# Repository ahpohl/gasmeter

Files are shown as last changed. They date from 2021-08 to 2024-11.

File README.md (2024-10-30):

# Overview

This project is about reading the counter of [diaphragm gas volume meter](https://en.wikipedia.org/wiki/Gas_meter) which is commonly installed in residential properties to count and bill the consumed gas. The last dial of the meter has a reflective sticker, which can be utilised to detect a full revolution of the dial.

In some meters the reflective sticker is made from a magnetic material and a very sensitive magnetometer is sufficient to detect the changes in the earth magnetic field when the sticker passes by the sensor. In the first version of this project used the [SparkFun 3-axis magnetometer](https://www.sparkfun.com/products/retired/12670) to detect a full revolution of the .001 m³ digit wheel. Since my gas meter was replaced with a new non-magnetic version, the magenetometer sensor doesn't work anymore.

Here I describe a new sensor device, which uses an infrared LED and a phototransistor to detect the changes in reflectivity when the reflective sticker on the last dial passes by the phototransitor. The measurement principle was inspired by the [pulsemeter](https://github.com/ahpohl/pulsemeter) and the device looks like this when mounted in front of the gas meter:

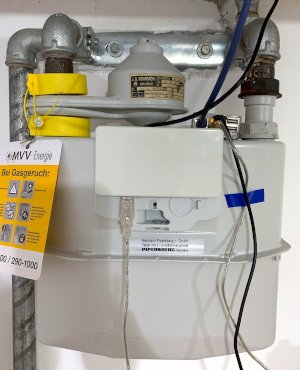
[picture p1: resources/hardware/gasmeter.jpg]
gasmeter


The schematics, board layout and part list of the gasmeter dongle hardware is described in more detail in the [Gasmeter wiki](https://github.com/ahpohl/gasmeter/wiki).

On the software side, the Gasmeter program reads the current gas volume from the meter and forwards it to a MQTT broker on the network. The data is stored in a TimescaleDB database and visualised on a Grafana dashboard. The installation of the software stack, including the setup and maintainance of the database, is described on the [Smartmeter](https://github.com/ahpohl/smartmeter/wiki) wiki pages.

## Build instructions

To compile Gasmeter from source, a Makefile for (cross-)compilation is provided:

```
make CROSS_COMPILE=aarch64-unknown-linux-gnu
make install
```

Alternatively, there is also an Arch Linux package called [gasmeter](https://aur.archlinux.org/packages/gasmeter) published in the AUR.

The hardware dongle needs firmware for the Atmel microcontroller in order to communicate with the gasmeter program. To compile the firmware, first install the AVR toolchain through your package manager. On Arch Linux, install `avr-gcc` and `avr-libc` packages and then `make upload` to compile and upload the firwmare. On a new microcontroller, a bootloader needs to be flashed first to accept a firmware image via upload. The preparation of a new µC is described in the [wiki](https://github.com/ahpohl/gasmeter/wiki).

## Installation

The Arch Linux package provides a systemd service file and installs the configuration file in `/etc/gasmeter/gasmeter.conf`. The service can be started with:

```
systemctl start gasmeter
```

When building directly from source, the daemon can be directly started with:

```
gasmeter --config resources/config/gasmeter_example.conf

```

## Run in Docker

The Arch Linux package installs a docker compose in `/etc/gasmeter/docker-compose.yaml` and a `Dockerfile`. Alternatively, these files are also in the root folder or the source. Before building and starting the container, the serial device used by the gasmeter hardware needs to be set in `docker-compose.yaml` in addtion to `gasmeter.conf` to give Docker access to the device.

```
docker-compose up --build
```

## Configuration

The Gasmeter program is configured with a configuration file located in `/etc/gasmeter/gasmeter.conf`. At least the serial device of the hardware, the MQTT hostname and topic to publish to needs to be set. Optionally, Gasmeter supports MQTT password authentication and TLS connection encryption. Finally, the gas tariff, which consists price per kWh, a yearly service charge and the gas conversion factor (found on the last bill), needs to be set here for the current bill to be shown on the dashboard.

On first run, the low and high threshold parameters need to be determined. For this, there is a special `raw_mode` option in the config file, which outputs the raw sensor values to the console. To record values create a log file with:

```
gasmeter --config gasmeter.conf | tee raw_values.log
```

Plotting the raw values gives a diagram like this (the gnuplot script is provided in the resources folder):

```
gnuplot < sensor.gnuplot > threshold_levels.png
```

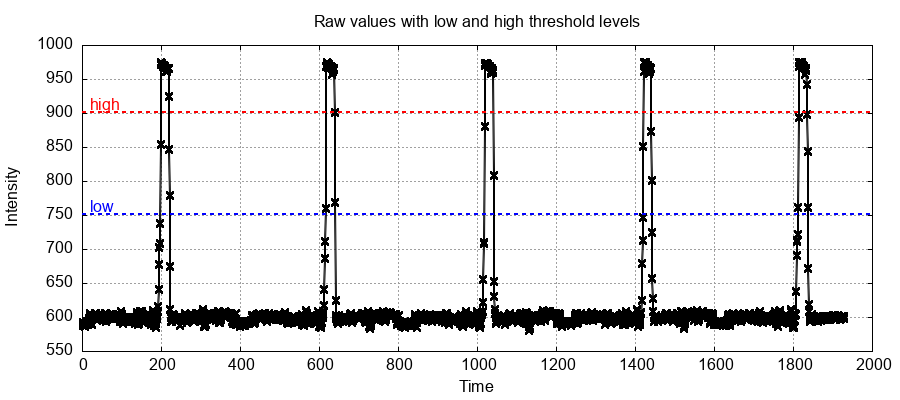
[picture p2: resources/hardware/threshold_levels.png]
Low and high threshold levels


The threshold level low needs to be set slightly above the baseline and level high below the maximum of the raw value. The larger the difference between the baseline and the maximum, the better the tolerance against noise and variations in reflected light intensity. Here the baseline is around 600 and the maximum at 950-1000 and a low level of 750 and high level of 900 works well.

A minimal `gasmeter.conf` config file looks like this:

```
serial_device /dev/ttyUSB0
mqtt_broker localhost
mqtt_topic gasmeter
gas_rate 261.80
gas_price 0.0583
gas_factor 10.835
level_low 750
level_high 900
```

## JSON output

Example JSON published by Gasmeter in the `gasmeter/live` topic:

```
{
  "time":1730287096822, # timestamp, secs since epoch
  "volume":4207.18,     # gas volume, m³ 
  "state":0,            # detection of volume change
  "rate":235.40,        # yearly service rate
  "price":0.1042,       # price per kWh, € (or whatever)
  "factor":11.048       # gas conversion factor, kWh*m³
}
```

## Future development

* Replace the host running gasmeter with an ESP32 version mounted directly on the PCB
* Web interface with MQTT and firmware download capability
* ESP32 version inspired by [AI-on-the-edge](https://github.com/jomjol/AI-on-the-edge-device) and the [Opentherm gateway](https://www.nodo-shop.nl/en/featured/211-opentherm-gateway.html)

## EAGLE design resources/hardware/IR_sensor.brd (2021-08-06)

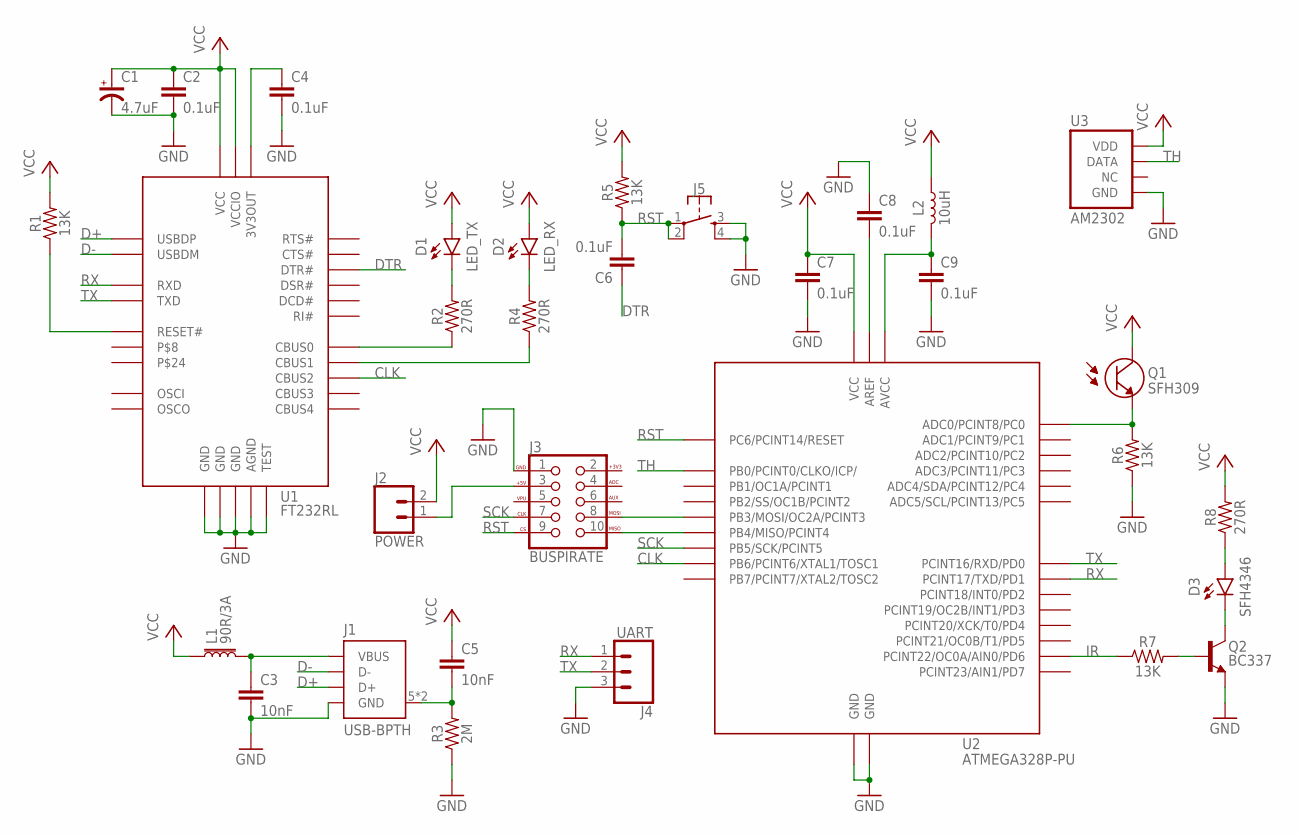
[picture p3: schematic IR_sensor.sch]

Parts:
C1: 4.7uF; CPOL-RADIAL-2.5MM-5MM
C2, C4, C6, C7, C8, C9: 0.1uF; CAP-PTH-5MM
C3: 10nF; CAP-PTH-2.5MM
C5: 10nF; CAP-PTH-5MM
D1: LED_TX; LED_5MM
D2: LED_RX; LED_5MM
D3: SFH4346; LED_3MM_R
J1: USB-BPTH; USB-B-PTH
J2: POWER; 1X02
J3: BUSPIRATE; 2X5-SHROUDED
J4: UART; 1X03
J5: SWITCH; TACTILE_SWITCH_PTH_6.0MM
L1: 90R/3A; AXIAL-0.3
L2: 10uH; AXIAL-0.4
Q1: SFH309; LED_3MM_R
Q2: BC337; TO-92
R1, R5, R6, R7: 13K; AXIAL-0.3
R2, R4, R8: 270R; AXIAL-0.3
R3: 2M; AXIAL-0.3
U1: FT232RL; TSSOP-28-BL
U2: ATMEGA328P-PU; DIP28
U3: AM2302; SNR4-2.54

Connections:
+3V3: J3.2 (+3V3)
ADC: Q1.A (E), R6.P$2 (2), U2.23 (ADC0/PCINT8/PC0)
CLK: U1.13 (CBUS2), U2.9 (PB6/PCINT6/XTAL1/TOSC1)
D+: J1.3 (D+), U1.15 (USBDP)
D-: J1.2 (D-), U1.16 (USBDM)
DTR: C6.1, U1.2 (DTR#)
GND: C1.2 (-), C2.2, C3.2, C4.2, C7.2, C8.1, C9.2, J1.4 (GND), J3.1 (GND), J4.3, J5.3, J5.4, Q2.1 (E), R3.P$1 (1), R6.P$1 (1), U1.7 (GND), U1.18 (GND), U1.21 (GND), U1.25 (AGND), U1.26 (TEST), U2.8 (GND), U2.22 (GND), U3.P$4 (GND)
IR: R7.P$1 (1), U2.12 (PCINT22/OC0A/AIN0/PD6)
MISO: J3.10 (MISO), U2.18 (PB4/MISO/PCINT4)
MOSI: J3.8 (MOSI), U2.17 (PB3/MOSI/OC2A/PCINT3)
unnamed: C3.1, J1.1 (VBUS), L1.P$2 (2)
unnamed: R1.P$1 (1), U1.19 (RESET#)
unnamed: C4.1, U1.17 (3V3OUT)
unnamed: D1.K, R2.P$2 (2)
unnamed: C8.2, U2.21 (AREF)
unnamed: D2.K, R4.P$2 (2)
unnamed: J2.1, J3.3 (+5V)
unnamed: D3.K, Q2.3 (C)
unnamed: R2.P$1 (1), U1.23 (CBUS0)
unnamed: C5.2, J1.5 (SHIELD), J1.6 (SHIELD), R3.P$2 (2)
unnamed: D3.A, R8.P$1 (1)
unnamed: Q2.2 (B), R7.P$2 (2)
unnamed: C9.1, L2.P$2 (2), U2.20 (AVCC)
unnamed: R4.P$1 (1), U1.22 (CBUS1)
RST: C6.2, J3.9 (CS), J5.1, J5.2, R5.P$1 (1), U2.1 (PC6/PCINT14/RESET)
RX: J4.1, U1.5 (RXD), U2.3 (PCINT17/TXD/PD1)
SCK: J3.7 (CLK), U2.19 (PB5/SCK/PCINT5)
TH: U2.14 (PB0/PCINT0/CLKO/ICP/), U3.P$2 (DATA)
TX: J4.2, U1.1 (TXD), U2.2 (PCINT16/RXD/PD0)
VCC: C1.1 (+), C2.1, C5.1, C7.1, D1.A, D2.A, J2.2, L1.P$1 (1), L2.P$1 (1), Q1.K (C), R1.P$2 (2), R5.P$2 (2), R8.P$2 (2), U1.4 (VCCIO), U1.20 (VCC), U2.7 (VCC), U3.P$1 (VDD)

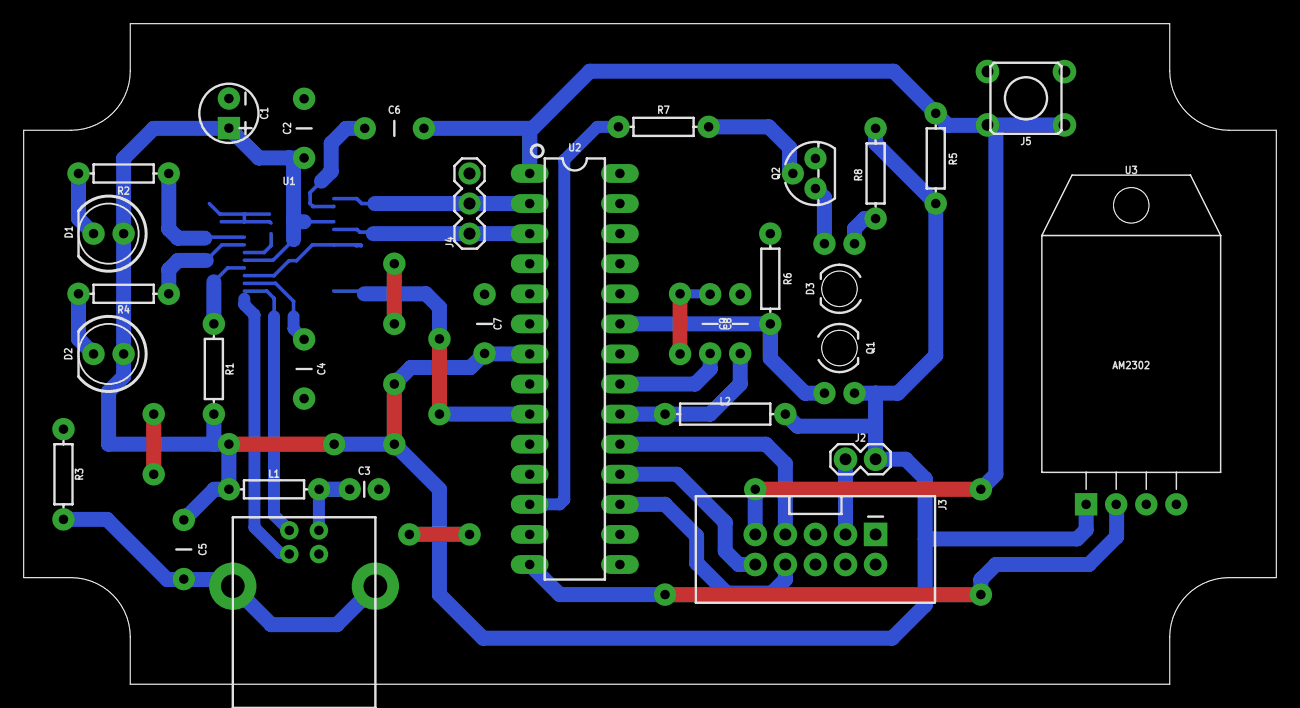
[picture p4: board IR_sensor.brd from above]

Board: 2 copper layers, 105.8 x 55.8 mm, 32 parts (0 on the bottom side), 29 nets.

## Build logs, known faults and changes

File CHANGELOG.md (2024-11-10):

# Gasmeter changelog

## v0.5.5 - 2024-11-10
* fix mqtt port config error

## v0.5.4 - 2024-10-30
* update documentation
* add docker compose support
* mqtt port optional argument
* fix compile errors
* add raw\_mode keyword in config
* calculate time buckets with local time zone

## v0.5.3 - 2023-03-24
* updated retention policies
* remove outer array in json output

## v0.5.2 - 2022-12-29
* fix mqtt status topic not retained
* automatically reconnect to broker

## v0.5.1 - 2022-10-29
* output current reading on startup

## v0.4.6 - 2022-04-02
* improved interrupt signal handling

## v0.4.5 - 2022-04-01
* removed DHT22 sensor code in firmware in daemon
* altered live database table

## v0.4.4 - 2022-03-30
* TimescaleDB: replaced \_time\_bucket() with timescaledb\_experimental.time\_bucket\_ng()
* created yearly\_view
* output state of gas flame in central heater

## v0.4.3 - 2022-01-03
* initial release
* add readme

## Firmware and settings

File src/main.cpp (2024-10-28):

#include <csignal>
#include <future>
#include <getopt.h>
#include <iostream>

#include <Gasmeter.h>

int main(int argc, char *argv[]) {
  bool version = false;
  bool help = false;
  std::string config;

  const struct option longOpts[] = {{"help", no_argument, nullptr, 'h'},
                                    {"version", no_argument, nullptr, 'V'},
                                    {"config", required_argument, nullptr, 'c'},
                                    {nullptr, 0, nullptr, 0}};

  const char optString[] = "hVc:";
  int opt = 0;
  int longIndex = 0;

  do {
    opt = getopt_long(argc, argv, optString, longOpts, &longIndex);
    switch (opt) {
    case 'h':
      help = true;
      break;
    case 'V':
      version = true;
      break;
    case 'c':
      config = optarg;
      break;
    default:
      break;
    }

  } while (opt != -1);

  if (help) {
    std::cout << "Gasmeter " << VERSION_TAG << std::endl;
    std::cout << std::endl << "Usage: " << argv[0] << " -c [file]" << std::endl;
    std::cout << "\n\
  -h --help         Show help message\n\
  -V --version      Show build info\n\
  -c --config       Set config file"
              << std::endl
              << std::endl;
    return EXIT_SUCCESS;
  }

  if (version) {
    std::cout << "Version " << VERSION_TAG << " (" << VERSION_BUILD
              << ") built " << VERSION_BUILD_DATE << " by "
              << VERSION_BUILD_MACHINE << std::endl;
    return EXIT_SUCCESS;
  }

  std::cout << "Gasmeter " << VERSION_TAG << " (" << VERSION_BUILD << ")"
            << std::endl;

  sigset_t sigset;
  sigemptyset(&sigset);
  sigaddset(&sigset, SIGINT);
  sigaddset(&sigset, SIGTERM);
  pthread_sigmask(SIG_BLOCK, &sigset, nullptr);

  std::atomic<bool> shutdown_requested(false);
  std::mutex cv_mutex;
  std::condition_variable cv;

  auto signal_handler = [&]() {
    int signum = 0;
    sigwait(&sigset, &signum);
    shutdown_requested.store(true);
    cv.notify_all();
    return signum;
  };

  auto ft_signal_handler = std::async(std::launch::async, signal_handler);

  std::unique_ptr<Gasmeter> meter(new Gasmeter());
  if (!meter->Setup(config)) {
    std::cout << meter->GetErrorMessage() << std::endl;
    return EXIT_FAILURE;
  }

  auto worker = [&]() {
    int timeout = 0;

    while (shutdown_requested.load() == false) {
      std::unique_lock lock(cv_mutex);
      if (!meter->Receive()) {
        if (timeout < 5) {
          std::cout << meter->GetErrorMessage() << std::endl;
          ++timeout;
        }
        continue;
      } else {
        timeout = 0;
      }
      if (!(meter->IsRawMode())) {
        if (!meter->Publish()) {
          std::cout << meter->GetErrorMessage() << std::endl;
        }
      }
      cv.wait_for(lock,
                  (meter->IsRawMode()) ? std::chrono::milliseconds(40)
                                       : std::chrono::seconds(60),
                  [&]() { return shutdown_requested.load(); });
    }
    return shutdown_requested.load();
  };

  auto worker_thread = (std::async(std::launch::async, worker));

  return EXIT_SUCCESS;
}

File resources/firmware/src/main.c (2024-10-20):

#include "main.h"
#include "gasmeter.h"
#include "millis.h"
#include "uart.h"
#include "util.h"
#include <avr/eeprom.h>
#include <avr/interrupt.h>
#include <avr/io.h>
#include <inttypes.h>
#include <stdio.h>
#include <stdlib.h>
#include <string.h>

// Interrupt service routine for the ADC completion
ISR(ADC_vect) {
  // must read low byte first
  gasmeter.adc_value = (int16_t)ADCL | ((int16_t)ADCH << 8);
}

void ReadAdc(void) {
  if (TCNT0 == (OCR0A + 8)) {
    // trigger single ADC measurement
    ADCSRA |= _BV(ADSC);
  }
}

void ReadGasMeter(void) {
  unsigned long current_millis = millis();
  static unsigned long previous_millis = 0;

  if (((current_millis - previous_millis) > 50)) {
    // evaluate counter
    static uint8_t hysteresis = 0;
    if ((gasmeter.adc_value > gasmeter.level_high)) {
      hysteresis = 1;
      // CLED_PORT &= ~(_BV(CLED_PIN));
    } else if ((gasmeter.adc_value < gasmeter.level_low) && hysteresis) {
      ADCSRA &= ~(_BV(ADEN));
      gasmeter.volume++;
      ADCSRA |= _BV(ADEN);
      eeprom_write_dword(&AddrVolume, gasmeter.volume);
      hysteresis = 0;
      // CLED_PORT |= _BV(CLED_PIN);
    }
    previous_millis = current_millis;
    // SendRaw(gasmeter.adc_value, gasmeter.volume, hysteresis);
  }
}

int main(void) {
  //
  // setup counter LED, optional
  //

  // set LED pin as output
  // CLED_DDR |= _BV(CLED_PIN);

  //
  // timer 0 for IR led PWM
  //

  // set OC0A pin as output, required for output toggling
  IRLED_DDR |= _BV(IRLED_PIN);

  // CLK/256 prescale value
  TCCR0B = _BV(CS02);

  // fast PWM mode, inverting mode
  // set OC0A on compare match, clear OC0A at BOTTOM
  // f = F_CPU/(256*prescaler)
  // f = 12 MHz/(256*256) = 184 Hz
  TCCR0A = _BV(WGM01) | _BV(WGM00) | _BV(COM0A1) | _BV(COM0A0);

  // duty cycle = 230 / 255 = 90 % off, 10 % on
  OCR0A = 230;

  //
  // ADC for reading IR phototransistor
  //

  // right adjust result, clear ADLAR bit
  ADMUX &= ~_BV(ADLAR);

  // select AVCC with external capacitor at AREF, set REFS0 bit
  ADMUX |= _BV(REFS0);

  // select ADC channel 0, clear MUX3..0 bits
  ADMUX &= 0xF0;

  // select CLK/128 prescale value, ADPS0..2
  // ADC freq = 93.5 kHz
  ADCSRA |= _BV(ADPS2) | _BV(ADPS1) | _BV(ADPS0);

  // enable ADC interrupt, set ADIE bit
  ADCSRA |= _BV(ADIE);

  // enable ADC, set ADEN bit
  ADCSRA |= _BV(ADEN);

  //
  // UART serial
  //

  // init uart library
  uart_init(UART_BAUD_SELECT(UART_BAUD_RATE, F_CPU));

  // init millis timer
  millis_init();

  // read defaults from eeprom
  gasmeter.volume = eeprom_read_dword(&AddrVolume);
  gasmeter.level_low = eeprom_read_word(&AddrLevelLow);
  gasmeter.level_high = eeprom_read_word(&AddrLevelHigh);

  // now enable global interrupt
  sei();

  //
  // main loop
  //

  for (;;) {
    // read IR sensor
    ReadAdc();

    // evaluate gasmeter volume
    ReadGasMeter();

    // receive packet from uart
    ReceivePacket();

    // process packet
    ProcessPacket();
  }
}

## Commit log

2019-10-14 setting data rate does not work
    [main.cpp]
2019-10-18 introduced some bugs during function cleanup
    [main.cpp]
2019-10-19 offset not negative, signed bit bug
    [main.cpp]
2019-12-01 gasmeter framework copied from pulsemeter
2019-12-07 setup interrupt and open i2c device
2019-12-07 output magnetic field working
2019-12-08 magnetic field as private member
2019-12-08 write raw magnetic field to rrd works
2020-02-02 rrdcached socket not found
2020-02-07 remove wiringpi, disable interrupt
2020-06-09 rrd and socket strncpy const build error
2020-08-13 publish MQTT magnetization
2020-08-21 read mag3110 @2.5Hz, mqtt @2Hz, rrd @300s
2020-08-21 fix rrd minimum one second step error
    [main.cpp]
2020-08-22 add influxdb insert statements
2020-08-29 add node red flow
2021-08-01 take solarmeter files and rename
    [archive.csv, data.csv]
2021-08-05 fix most compiler errors
    [GasmeterFirmware.cpp]
2021-08-06 add eagle schematics and cam files
    [IR_sensor.brd, IR_sensor.sch]
2021-08-22 report uart error codes
    [gasmeter.c]
2021-08-22 disable hupcl modem reset after hangup
    [gasmeter.c, util.c]
2021-08-22 add millis timer
2021-08-22 wait for reset of avr on first connect
    [main.c]
2021-08-22 transfer singed int failed
    [gasmeter.c, util.c]
2021-08-24 read dht sensor payload
2021-08-24 dht22 sensor working
2021-08-25 set logging framework
2021-08-26 fix segfault config no value
    [GasmeterFirmware.cpp]
2021-08-28 send adc value, gnuplot sensor.plot
2021-09-03 use fast PWM
2021-09-04 send adc value using millis timer
2021-09-04 delay ADC start until signal is stable
2021-09-04 IR led PWM 10 % duty cycle
2021-09-04 no raw adc output
2021-09-04 fixed adc raw output
    [gasmeter.c, main.c]
2021-09-08 update grafana dashboard and node red flow
2021-09-10 update node red and grafana flows
2021-09-16 wait before reading next adc value
2021-09-19 gasmeter is counting too fast
    [main.c]
2021-11-05 counter correct, but don't know why
    [main.c]
2021-11-05 remove adc ready flag, counts working
2021-11-05 move counter eval to adc isr
2021-11-05 remove comp timer A interrupt
2021-11-06 use ADC prescaler CLK/128 93.5 kHz
2021-11-06 disbable global interrupts
2021-11-06 disable ADC interrupt when accessing gasmeter
2021-11-07 fixed theshold level bug
    [gasmeter.c, main.c, util.c]
2021-11-08 Revert "update eeprom instead of write"
    This reverts commit 7ea6cabdc72cd090f58773e36a6eabbb8c77c535.
    [main.c]
2021-11-14 add optional counter led
2021-11-14 disable counter led
2021-11-16 sink current for counter led
2022-01-08 pg: use experimental time bucket function
2022-02-02 add unique constraint on archive bucket_1d
2022-03-30 update node flow and grafana
2022-03-31 increase main thread wait to 60 seconds
2022-04-01 use condtion variables and threads in main
2022-04-02 clean up worker thread
2022-04-02 remove thread vector
2022-10-29 output current meter reading
2023-03-24 remove array in node-red flow
2023-04-15 time buckets with local time zone
2024-10-28 serial and raw logging broken
    [GasmeterFirmware.cpp]
2024-10-28 print send while logging
2024-10-30 sensor.gnuplot set precision
